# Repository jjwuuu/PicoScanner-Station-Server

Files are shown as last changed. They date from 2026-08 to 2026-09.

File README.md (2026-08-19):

# PicoScanner Station Server

PicoScanner is an RFID check-in system for makerspaces and similar shared spaces. Raspberry Pi Pico W readers send card swipes to a Raspberry Pi 3 server, which provides a live dashboard, card database, certifications, station rules, and CSV exports.

## What it does

- Tracks entry and exit through doors.
- Tracks active use of equipment stations without changing the building count.
- Requires active card records and station certifications where configured.
- Limits regular User entry to opening hours (12:00 PM-5:00 PM by default).
- Allows Admin, Staff, and Volunteer accounts to enter after hours.
- Automatically closes a station session when a person exits the building.
- Records swipe history and administrative actions for reporting.
- Provides Admin-only live usage analytics and Excel/CSV exports.

## Project layout

```text
Code/
  Pi 3/       Flask server, dashboard, configuration, and test-data sender
  Pico W/     MicroPython reader firmware and RFID helpers
```

## Server setup (Raspberry Pi 3)

```bash
cd "Code/Pi 3"
python -m venv venv
source venv/bin/activate
pip install -r requirements.txt
```

Set secure credentials before starting the server:

```bash
export STATION_API_KEY='replace-with-one-shared-reader-key'
export STATION_BOOTSTRAP_ADMIN_CARD_ID='your-admin-card-id'
export STATION_BOOTSTRAP_ADMIN_PASSWORD='choose-a-strong-password'
export STATION_TIMEZONE='America/Los_Angeles'
export STATION_OPENING_HOUR='12'
export STATION_CLOSING_HOUR='17'
python app.py
```

Open the dashboard at `http://<pi-address>:5000/dashboard`.

The default station configuration is in [`Code/Pi 3/config.json`](Code/Pi%203/config.json). Edit it to add, rename, or remove doors and stations before deployment.

## Dashboard roles

| Role | Capabilities |
| --- | --- |
| Admin | Manages dashboard accounts, station rules, certification permissions, cards, certifications, swipe history, and audit history. |
| Staff | Manages station rules, cards, certifications, and swipe history. |
| Volunteer | Manages cards and assigned certifications. |
| Public | Views high-level live occupancy and station activity only. |

## Pico W reader setup

Use the reader firmware in `Code/Pico W` as a starting point:

- `door_pico.py` is for entry/exit readers.
- `soldering_station_pico.py` is an equipment-station example.

Update these values in each firmware file before copying it to a Pico W:

```python
SERVER_URL = "http://<pi-address>:5000/swipe"
STATION_API_KEY = "replace-with-one-shared-reader-key"
STATION_ID = "soldering"
STATION_NAME = "Soldering Station"
STATION_KIND = "station"  # use "door" for doors
```

Every reader must use the same `STATION_API_KEY` configured on the server. Each station ID must match an entry in `config.json`.

## Opening hours

Regular User cards can enter from 12:00 PM up to 5:00 PM. Admin, Staff, and Volunteer accounts can enter outside that window. Exits are always allowed. Change the hours with `STATION_OPENING_HOUR` and `STATION_CLOSING_HOUR`; both use 24-hour whole-hour values.

## Analytics and exports

The Admin tab shows live station rankings, total usage time, completed sessions, unique station users, busiest times, and authorized after-hours activity. Choose a 7, 30, or 90-day range, or all time. The view refreshes automatically while open.

The server stores its SQLite database beside `app.py`. Admins can download a master Excel workbook with separate People, Certifications, Cards, Pending Canvas, Swipe Log, Audit Log, Station Analytics, and After Hours sheets. Individual CSV exports remain available for focused reporting:

- `/swipes.csv` — swipe history
- `/active.csv` — people currently inside
- `/station_status.csv` — current station use
- `/audit.csv` — administrative audit history

Only Admin sessions can export CSV data from the site.
The master workbook is a reporting snapshot. Continue using the original wide Canvas CSV for Canvas imports.

## Production notes

- Use a strong, unique API key and administrator password.
- Keep the Pi server on a trusted network.
- Login protection is enforced server-side: repeated failures are limited per username/IP pair, per username across IPs, and per IP across usernames.
- Login error messages do not reveal whether an account exists, and failed-login audit entries are throttled to prevent log flooding.
- Each account may keep up to three active dashboard sessions; older tokens are invalidated automatically.
- Browser writes from a different origin are rejected, and HTTPS responses include strict transport and isolation headers.
- Configure the supplied `station-server.service` file if the server should start automatically after boot.
- Back up the SQLite database before upgrades or schema changes.

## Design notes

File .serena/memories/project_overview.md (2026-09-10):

PicoScanner is an RFID makerspace access and station-use system. Serena project root is C:\Users\xtras\jwuuu07.github.io\PicoScanner; live code is under Code, with no Code\Original directory despite the session cwd metadata. Main server files are Code\Pi 3\app.py, dashboard.html, config.json, requirements.txt, station-server.service, test_app.py, and seed_analytics_demo.py. The backend is a single large Flask app using SQLite, openpyxl exports, in-memory login sessions, certification timers, and kit swipe-pair timers. Main API surfaces include /swipe, /api/test-swipe, /health, /dashboard, /api/dashboard, /api/access, /api/admin, card/station/certification/kit endpoints, analytics, XLSX export, and CSV exports. Database tables are created in init_db and include stations, active_people, active_sessions, people, cards, user_accounts, certifications, bronco_certifications, certify_permissions, canvas_sync_tasks, swipe_events, pending_card_dismissals, warning_dismissals, audit_log, kits, and kit_checkouts. Pico W firmware lives in Code\Pico W. Reader scripts share MFRC522 RFID reads, a limit switch trigger, NeoPixel LED states, optional GP14 buzzer feedback, HTTP POSTs to the Flask /swipe endpoint with X-Station-Key, event_id idempotency, and OfflineQueue retry storage. Repeated station readers are specialized mainly by STATION_ID, STATION_NAME, and STATION_KIND. Key helpers are mfrc522.py and offline_queue.py. Tests are unittest-based in Code\Pi 3\test_app.py and cover security, login rate limiting, role enforcement, swipe idempotency, dashboard privacy, certifications, station sessions, kit checkout, Canvas import/sync, exports, warnings, and analytics-relevant flows. README test command is ./venv/bin/python -m unittest -v test_app.py from Code\Pi 3 on the Pi. Deployment uses gunicorn with one worker and four threads because server-side sessions/timers are in memory. Operational caution: several Pico scripts contain placeholder or literal test Wi-Fi/API key values such as MS, Ms2019!!, and key; avoid committing or deploying real secrets in these files.

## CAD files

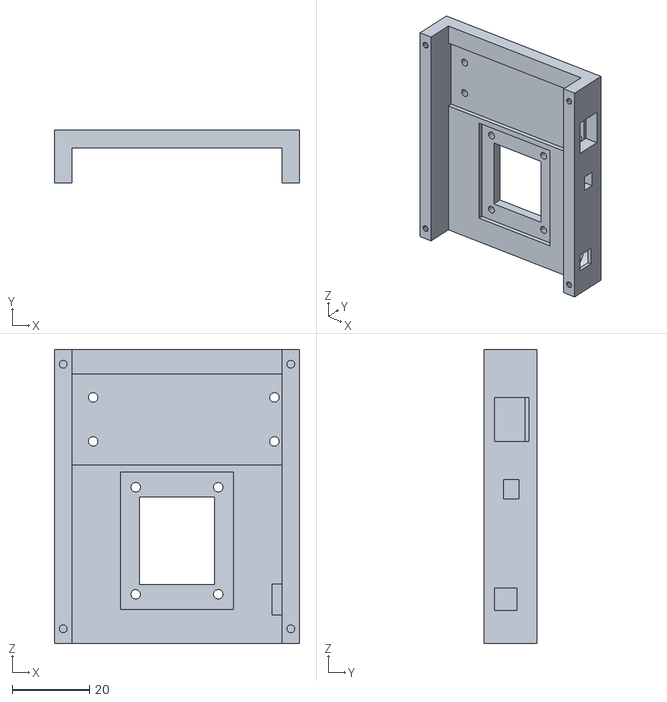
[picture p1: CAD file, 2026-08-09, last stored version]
Model/ScannerCaseV1/Scanner_Mod_Switch_Mod.stl
63.5 x 13.8 x 76.2

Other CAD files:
Model/ScannerCaseV1/OldVersions/Base.0001.ipt
Model/ScannerCaseV1/OldVersions/Base.ipt
Model/ScannerCaseV1/OldVersions/RFID_Bottom.0014.ipt
Model/ScannerCaseV1/OldVersions/RFID_Test.0007.ipt
Model/ScannerCaseV1/OldVersions/Scanner_Mod_Switch.0019.ipt
Model/ScannerCaseV1/OldVersions/Scanner_Test_Bot.0013.ipt
Model/ScannerCaseV1/OldVersions/Scanner_Test_Middle.0009.ipt
Model/ScannerCaseV1/OldVersions/Scanner_Test_Top.0006.ipt
Model/ScannerCaseV1/OldVersions/Scanner_Test_Top_2.0009.ipt
Model/ScannerCaseV1/OldVersions/Scanner_Top.0010.ipt
Model/ScannerCaseV1/OldVersions/Scanner_Top.0012.ipt
Model/ScannerCaseV1/OldVersions/Scanner_Top_Switch - Copy.0013.ipt
Model/ScannerCaseV1/OldVersions/Switch.0019.ipt
Model/ScannerCaseV1/PicoTest.ipt
Model/ScannerCaseV1/RFID_Bottom.ipt
Model/ScannerCaseV1/Scanner_Mod_Switch.ipt
Model/ScannerCaseV1/Scanner_Mod_Switch_Mod.ipt
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

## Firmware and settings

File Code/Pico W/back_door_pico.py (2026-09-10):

import machine
from machine import Pin
import neopixel
import network
import time
import ujson
from ubinascii import hexlify

try:
    import urequests
except ImportError:
    urequests = None

from mfrc522 import MFRC522
from offline_queue import OfflineQueue


# Edit these for your hotspot and Pi server.
WIFI_SSID = "replace-with-hotspot-ssid"
WIFI_PASSWORD = "replace-with-hotspot-password"
SERVER_URL = "http://192.168.1.60:5000/swipe"
STATION_API_KEY = "replace-with-station-api-key"

# Back entrance reader.
DOOR_ID = "back-door"
DOOR_NAME = "Back Door"
STATION_KIND = "door"

# Hardware pins. These match the newer wiring in test.py.
LIMIT_SWITCH_PIN = 5
NEOPIXEL_PIN = 13

# Optional piezo buzzer. Wire + to GP14 and - to GND.
# Set to None to disable the buzzer without changing the rest of the reader.
BUZZER_PIN = 14

RFID_SCK = 18
RFID_MISO = 16
RFID_MOSI = 19
RFID_CS = 20
RFID_RST = 22


reader = MFRC522(
    spi_id=0,
    sck=RFID_SCK,
    miso=RFID_MISO,
    mosi=RFID_MOSI,
    cs=RFID_CS,
    rst=RFID_RST,
)
queue = OfflineQueue()
event_counter = 0
QUEUE_RETRY_MS = 10000
next_queue_retry = 0

limit_switch = Pin(LIMIT_SWITCH_PIN, Pin.IN, Pin.PULL_UP)
pixel = neopixel.NeoPixel(Pin(NEOPIXEL_PIN), 1)
buzzer = machine.PWM(Pin(BUZZER_PIN)) if BUZZER_PIN is not None else None
if buzzer:
    buzzer.duty_u16(0)

COLORS = {
    "off": (0, 0, 0),
    "green": (0, 60, 0),
    "yellow": (60, 45, 0),
    "blue": (0, 0, 80),
    "cyan": (0, 50, 50),
    "red": (80, 0, 0),
    "purple": (45, 0, 60),
}


def set_led(color):
    pixel[0] = COLORS[color]
    pixel.write()


def beep(frequency, duration_ms):
    if buzzer is None:
        return
    buzzer.freq(frequency)
    buzzer.duty_u16(32768)
    time.sleep_ms(duration_ms)
    buzzer.duty_u16(0)


def play_buzzer_signal(signal, action=""):
    if signal == "unknown_card":
        beep(660, 90)
        time.sleep_ms(70)
        beep(440, 150)
    elif signal == "access_denied":
        beep(330, 250)
    elif signal == "server_error":
        beep(220, 180)
    elif action == "enter":
        beep(880, 80)
        time.sleep_ms(50)
        beep(1175, 120)
    elif action == "exit":
        beep(520, 120)
    elif signal == "access_granted":
        beep(880, 120)


def blink(color, count=3, delay=0.15):
    for _ in range(count):
        set_led(color)
        time.sleep(delay)
        set_led("off")
        time.sleep(delay)


def limit_pressed():
    # Pull-up wiring: pressed/closed switch reads 0.
    return limit_switch.value() == 0


def connect_wifi():
    wlan = network.WLAN(network.STA_IF)
    wlan.active(True)

    if wlan.isconnected():
        return wlan

    set_led("yellow")
    wlan.connect(WIFI_SSID, WIFI_PASSWORD)

    start = time.time()
    while not wlan.isconnected():
        if time.time() - start > 20:
            blink("purple", 4)
            return wlan
        time.sleep(0.25)

    set_led("green")
    print("Wi-Fi connected:", wlan.ifconfig())
    return wlan


def event_for(card_id):
    global event_counter
    event_counter += 1
    return "%s-%s-%s" % (hexlify(machine.unique_id()).decode(), time.ticks_ms(), event_counter)


def post_event(data):
    body = ujson.dumps(data)
    response = urequests.post(SERVER_URL, data=body, headers={"Content-Type": "application/json", "X-Station-Key": STATION_API_KEY})
    text = response.text
    response.close()
    return ujson.loads(text)


def resend_queued():
    global next_queue_retry
    if urequests is None or not wlan.isconnected():
        return

    now = time.ticks_ms()
    if time.ticks_diff(now, next_queue_retry) < 0:
        return
    next_queue_retry = time.ticks_add(now, QUEUE_RETRY_MS)

    event = queue.peek()
    if not event:
        return
    try:
        post_event(event)
        queue.remove_first()
        print("Queued swipe delivered; remaining:", len(queue))
    except Exception as error:
        print("Queued swipe server retry failed:", repr(error))


def send_swipe(card_id):
    if urequests is None:
        print("urequests is not installed")
        blink("purple", 4)
        return {"led_signal": "server_error", "error": "urequests is not installed"}

    data = {
        "card_id": str(card_id),
        "station_id": DOOR_ID,
        "station_name": DOOR_NAME,
        "station_kind": STATION_KIND,
        "event_id": event_for(card_id),
    }

    try:
        print("Sending swipe to:", SERVER_URL)
        result = post_event(data)
        print("Server response:", result)
        if not result.get("ok", False):
            result["led_signal"] = "server_error"
        return result
    except Exception as error:
        print("Server error:", repr(error))
        pending = queue.add(data)
        print("Swipe queued; pending:", pending)
        return {
            "led_signal": "server_error",
            "queued": True,
            "error": "Swipe queued for retry",
        }


def read_card_and_send(reads=6, required_hits=2):
    counts = {}

    for _ in range(reads):
        status, _tag_type = reader.request(reader.REQIDL)

        if status == reader.OK:
            status, uid = reader.SelectTagSN()

            if status == reader.OK:
                card_id = str(int.from_bytes(bytes(uid), "little", False))
                counts[card_id] = counts.get(card_id, 0) + 1
                print("CARD ID:", card_id)

                if counts[card_id] >= required_hits:
                    return send_swipe(card_id)

        time.sleep(0.08)

    return None


def show_result(result):
    if not result:
        return

    signal = result.get("led_signal", "")
    action = result.get("action", "")
    play_buzzer_signal(signal, action)
    if signal == "server_error" or result.get("queued"):
        blink("purple", 3)
        return

    if signal == "unknown_card":
        blink("purple", 3)
        return

    if signal == "access_denied":
        blink("red", 3)
        return

    action = result.get("action")

    if action == "enter":
        set_led("blue")
        time.sleep(1)
    elif action == "exit":
        set_led("cyan")
        time.sleep(1)
    else:
        print("Unexpected server result:", result)
        blink("purple", 3)


def wait_for_release():
    while limit_pressed():
        time.sleep(0.05)
    time.sleep(0.2)


reader.init()
wlan = connect_wifi()
set_led("green" if wlan.isconnected() else "purple")

print(DOOR_NAME, "scanner ready")

while True:
    if not wlan.isconnected():
        wlan = connect_wifi()
    else:
        resend_queued()

    if limit_pressed():
        set_led("yellow")
        result = read_card_and_send()

        if result:
            show_result(result)
        else:
            blink("red", 2)

        set_led("green" if wlan.isconnected() else "purple")
        wait_for_release()

    time.sleep(0.05)

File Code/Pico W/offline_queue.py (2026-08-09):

"""Small durable FIFO queue for MicroPython RFID readers."""
import os
import ujson


class OfflineQueue:
    def __init__(self, path="swipe_queue.json", max_items=100):
        self.path = path
        self.max_items = max_items

    def _load(self):
        try:
            with open(self.path, "r") as file:
                return ujson.load(file)
        except Exception:
            return []

    def _save(self, items):
        temp = self.path + ".tmp"
        with open(temp, "w") as file:
            ujson.dump(items, file)
        try:
            os.remove(self.path)
        except OSError:
            pass
        os.rename(temp, self.path)

    def add(self, event):
        items = self._load()
        items.append(event)
        # Keep newest events if flash storage is exhausted.
        self._save(items[-self.max_items:])
        return len(items[-self.max_items:])

    def peek(self):
        items = self._load()
        return items[0] if items else None

    def remove_first(self):
        items = self._load()
        if items:
            self._save(items[1:])

    def __len__(self):
        return len(self._load())

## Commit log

2026-08-09 Initial sanitized PicoScanner upload
    [Base.0001.ipt, Base.ipt, PicoTest.ipt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]
2026-08-19 Update README and Pico station files
